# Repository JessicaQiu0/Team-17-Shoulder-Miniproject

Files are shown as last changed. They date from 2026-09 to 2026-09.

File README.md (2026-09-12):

# 03-Miniproject-2026-27

This is a template repo for a multi-disciplinary mini-project for a
small team of EEs, CEs, MEs, and BMEs. The mini-project is described in the
course assignment. You should tailor this repo based on your team
composition, roles, and the tasks at hand.

---

## Team

| Role | Named Members |
|---|---|
| Mechanical Engineering | Elaine Zeng, Marissa Zhai, Sara Mcdermott|
| Electrical Engineering | Jessica Qiu |
| Computer Engineering | Dakota Wang, Melinda Tran|
| Biomedical Engineering | NA |

---

## Repository Structure

```
.
├── firmware/          # Micro source code
├── hardware/
│   ├── electrical/    # Schematics, wiring diagrams, and BOM
│   └── mechanical/    # Enclosure CAD files and fabrication notes
└── docs/              # Project documentation 
```

---

## Hardware

| Component | Notes |
|---|---|
| Seeed XIAO ESP32-S3 | Main microcontroller, runs MicroPython |
| 28BYJ-48 stepper motor | 5-wire, 4-phase unipolar, drives clock hand |
| L293D H-bridge driver | Level-shifts 3.3V logic to 5V motor power |
| RGB LED (common cathode, 4-pin) | PWM-driven per color channel, indicates timer state |
| 2× tactile switches | Preset select + start/pause/reset control |

---

## Team Responsibilities 
Any discipline can do any role here -- you make the assigments. 

### Mechanical oriented
- Design the enclosure 
- Fabricate the enclosure (3-D print or laser-cut)
- Document the assembly process 

### Electrical oriented
- Produce the breadboard schematic
- Summarize the bill of materials
- Wire the circuit on the breadboard, verfify that the componets are assembled correctly, validate the voltage levels

### Computer oriented
- Design the software based on the required functionality
- Develop MicroPython code and firmware 
- Flash and test the firmware on the target micro
- Document the APIs for the system

## Deliverables

- [ ] Functional MicroPython firmware
- [ ] Completed breadboard assembly per schematic
- [ ] Fabricated and assembled enclosure (if MEs on team)
- [ ] Documentation in this repository
- [ ] Video recording demonstrating required function (stored in google drive)

## Contribution Workflow

We want each team member to contribute work products and to host these
including documentation in the repo with version control (software,
firmware, schematics, BOMs, CAD models, etc.) All can be managed in
the repo with version control.

1. Establish that each teammember has properly set up Git/GitHub Desktop
2. Decompose the project into units to assign to each named team member 
3. From the team repo, create a branch from `main` named `<role>/<feature>` (e.g., `me/case`) to capture work artifacts 
4. Fetch the branch to the local laptop
5. Each team member does their work and produces work artifacts and commits these changes to the branch
6. Commit changes with descriptive messages
7. Open a pull request and request review from at least one other team member
8. Merge to main after approval

When performed properly, this workflow leads to an organized set of
work products that are developed concurrently and collaboratively with
version control. This includes the products themselves (e.g.,
firmware, CAD, schematics, etc.) and the associated documentation

Don't know how to do this? Ask your ECE teammates, GSTs, instructors, or AI. 

---

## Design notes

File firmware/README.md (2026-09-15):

# Software README

## Overview
This folder contains the MicroPython firmware for the meeting timer!

There are two main firmware files:

- `main.py` - standard meeting timer firmware (launches `timer_fsm.py` and `stepper_driver.py`)
- `timer_fsm.py` - timer state machine, button debouncing, and PWM breathing logic
- `stepper_driver.py` - motor driver and stepping sequence routines
- `main_low_power.py` - meeting timer firmware with added low-power behavior (When the timer is not actively running, the ESP32 enters short 50 ms light sleep periods to reduce power use while still remaining responsive to button presses and LED updates)
- `full_main.py` - complete, unified meeting timer firmware implementing hardware initialization, event loops, finite state machine transitions, dynamic step tracking, and PWM breathing routines`

The firmware controls:
- the stepper motor
- two push buttons
- three LEDs
- timer preset selection
- countdown behavior
- pause/resume behavior
- reset behavior

The timer supports four preset times:
- 15 minutes
- 20 minutes
- 25 minutes
- 30 minutes

## Pin Assignments

| Component | GPIO Pin |
|---|---:|
| Stepper Motor Coil 1 | GPIO 1 |
| Stepper Motor Coil 2 | GPIO 2 |
| Stepper Motor Coil 3 | GPIO 3 |
| Stepper Motor Coil 4 | GPIO 4 |
| Button 1 | GPIO 5 |
| Button 2 | GPIO 6 |
| Blue LED | GPIO 7 |
| Red LED  | GPIO 8 |
| Green LED| GPIO 9 |

## Controls

### Button 1
Button 1 cycles through the preset timer values:

15 → 20 → 25 → 30 → 15

When a preset is selected, the stepper motor moves the clock hand to the corresponding position.

### Button 2
Button 2 controls the timer:

A short press:
- starts the timer
- pauses the timer while running
- resumes the timer while paused
- resets the timer after it finishes

Holding Button 2 for 2 seconds resets the timer and moves the hand back to 0.

## LED States
The LEDs indicate the current timer state:

- Blue: selecting a preset or paused
- Green: countdown running
- Red: countdown finished

The LEDs are controlled using PWM so the active LED pulses instead of remaining constantly on.

## Timer States

The firmware uses four states:

```python
SELECTING = 0
RUNNING = 1
PAUSED = 2
FINISHED = 3

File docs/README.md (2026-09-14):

# Project Documentation

## Contents

| File | Description |
|---|---|
| project_overview.md | High-level goals, description, usage, and deliverables |
| Mini project photo.jpeg | Photo of the completed device |

---

## Quick Links

- [Firmware](../firmware/)
- [Electrical](../hardware/electrical/)
- [Enclosure](../hardware/mechanical/)

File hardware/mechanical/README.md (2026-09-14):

# Mechanical

## Contents

| File | Description |
| --- | --- |
| `Box.stl` | 3D-printable enclosure body |
| `Assembly 1.stl`  | Complete enclosure assembly for visualization and fit checking |
| `Box Drawing.dxf` | 2D drawing of the enclosure body |
| `Lid Drawing.dxf` | 2D drawing of the enclosure lid |
| `Lid DXF.dxf` | Clock face design used for engraving the lid |
| `Pointer.dxf` | DXF used to cut popsicle stick |

## Overview

The mechanical design consists of a 3D-printable enclosure and lid that house the timer's electrical components and support the stepper motor used to drive the mechanical countdown display.

The enclosure was designed to keep the overall construction simple while providing the necessary mounting and access features for the electronics. The design includes a pathway for the external USB-C cable and a secure mounting location for the stepper motor.

To give the device the appearance of a physical clock rather than a generic electronics enclosure, the team decided to use a clock-inspired aesthetic. A clock face was added to the lid as an engraving, with the stepper motor positioned so that its shaft can drive the external clock hand. The popsicle stick was laser cut to be shorter to accommodate the LED and have a tip that aligns with the clock ticks.

## Enclosure Design

### Box

The box forms the main body of the enclosure and provides space for the microcontroller, motor driver, wiring, and other electrical components.

The enclosure was designed with the following considerations:

* Sufficient internal space for the electrical components and wiring
* A pathway for the USB-C cable for power and programming
* Simple geometry to make the enclosure easy to manufacture and assemble
* Compatibility with the separate lid

The printable enclosure geometry is provided in `Box.stl`, while `Box Drawing.dxf` contains the corresponding 2D drawing.

### Lid

The lid closes the enclosure and serves as the visible clock face of the timer. It includes the features needed to integrate the mechanical countdown display with the enclosure.

The lid was designed to:

* Support the stepper motor securely
* Allow the motor shaft to extend through the lid and connect to the clock hand
* Provide a clock-style front face for the timer
* Fit with the main enclosure for assembly

The lid drawing is provided in `Lid Drawing.dxf`.

## Clock Face

The team decided to give the enclosure a clock-inspired appearance to better communicate the timer's function.

A clock face design was created for engraving onto the lid. This adds numerical markings directly to the enclosure rather than requiring separate labels or components.

The engraving geometry is provided in `Lid DXF.dxf`.

## Stepper Motor Integration

The enclosure is designed around the 28BYJ-48 stepper motor used for the timer's mechanical countdown display.

The motor is mounted to the lid so that its output shaft passes through the clock face. A clock hand can then be attached to the shaft and rotated as the timer counts down.

The motor mounting geometry was designed to keep the motor securely positioned and aligned with the center of the clock face.

## Assembly

The complete enclosure consists of the box, lid, stepper motor, internal electronics, and external clock hand.

`Assembly 1.stl` provides the assembled geometry and can be used to visualize the completed enclosure and verify the relationship between the individual mechanical components.

## Manufacturing and Assembly Notes

The box and lid are designed to be 3D printed as separate components.

Before final assembly:

1. Check that the stepper motor fits correctly in its mounting location.
2. Verify that the motor shaft is aligned with the center of the clock face.
3. Confirm that the USB-C cable can pass through the enclosure without interference.
4. Install the electrical components and route the wiring inside the enclosure.
5. Attach the lid to the enclosure.
6. Attach the clock hand to the stepper motor shaft.

The clock face engraving should be added to the lid before final assembly.

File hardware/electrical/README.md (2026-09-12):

# Electrical

## Contents

| File | Description |
|---|---|
| `Electrical_Schematic.pdf` | Full circuit schematic |
| `Electrical_Schematic.kicad_sch` | Editable KiCad source file |

## Overview

This circuit implements a timer with a mechanical countdown display. A user selects a preset time (15/20/25/30 min) and starts the timer using two buttons. As time counts down, a stepper motor rotates a clock hand to show time remaining, while an RGB LED pulses to indicate the timer's status (e.g., running, paused, or finished).

**Motor control:** Since the XIAO's GPIO pins output 3.3V and can't directly drive the motor, an L293D H-bridge driver sits between them. It takes the 3.3V logic signals and switches the motor's 5V power accordingly. The stepper is driven using wave-pulse sequencing (energizing one coil at a time in sequence) to rotate the clock hand.

**LED feedback:** A common-cathode RGB LED, current-limited with 220Ω resistors on each color leg, is PWM-driven by the microcontroller to pulse and change color based on timer state.

**User input:** Two push buttons let the user select a preset and control start/pause/reset, read directly by the microcontroller's GPIO pins.

## Pin Mapping

### XIAO ESP32-S3 → L293D (motor control)

| XIAO Pin | L293D Pin | Function |
|---|---|---|
| GPIO1 | Pin 2 (1A) | Motor coil 1 signal |
| GPIO2 | Pin 7 (2A) | Motor coil 2 signal |
| GPIO3 | Pin 10 (3A) | Motor coil 3 signal |
| GPIO4 | Pin 15 (4A) | Motor coil 4 signal |

### L293D → Motor (28BYJ-48)

| L293D Pin | Motor Wire |
|---|---|
| Pin 3 (1Y) | Orange (Coil 1) |
| Pin 6 (2Y) | Pink (Coil 2) |
| Pin 11 (3Y) | Yellow (Coil 3) |
| Pin 14 (4Y) | Blue (Coil 4) |
| — | Red (+5V, direct to 5V rail) |

### XIAO ESP32-S3 → RGB LED (via 220Ω resistors)

| XIAO Pin | LED Leg |
|---|---|
| GPIO7 | Blue |
| GPIO8 | Red |
| GPIO9 | Green |
| GND/13 | Common leg → GND |

### XIAO ESP32-S3 → Buttons

| XIAO Pin | Button |
|---|---|
| GPIO5 | Button 1 (other leg → GND) |
| GPIO6 | Button 2 (other leg → GND) |

### Power & Ground

| XIAO Pin | Connects To |
|---|---|
| 3.3V | L293D VCC1 (Pin 16), EN1,2 (Pin 1), EN3,4 (Pin 9) |
| 5V | L293D VCC2 (Pin 8), Motor Red wire |
| GND | L293D GND (Pins 4, 5, 12, 13), LED common leg, both buttons |

## Bill of Materials

| Part | Qty | Source | Unit Cost | Notes |
|---|-----|---|---|---|
| Seeed XIAO ESP32-S3 | 1 | Digikey | $7.49 | Main microcontroller |
| L293D H-bridge driver | 1 | Digikey | $8.86 | Level-shifts 3.3V logic to 5V motor power |
| 28BYJ-48 stepper motor | 1 | Adafruit | $4.95 | Drives clock hand; no clean single-unit listing found |
| RGB LED (common cathode, 4-pin) | 1 | Digikey | $2.66 | PWM-driven, indicates timer state |
| Tactile switch | 2 | Digikey | $0.10 | Button 1 (preset select), Button 2 (start/pause/reset) |
| 220Ω resistor | 3 | Digikey | $0.10| LED current limiting |
| USB-C cable | 1 | — | — | Power + programming |
| Popsicle stick | 1 | — | — | Clock hand |
| Jumper wires | — | — | — | Breadboard connections |

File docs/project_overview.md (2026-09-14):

# Project Overview

## Goal

Build a self-contained meeting timer with a mechanical display. The device lets a user select a preset duration, start/pause/reset the countdown, and see time remaining via a rotating clock hand while an RGB LED indicates the timer's current status. This project help our team to establish our GitHub workflow, collaborative process, and hardware-software development environment ahead of our Senior Design project.

## Description of Device

The meeting timer is built around a Seeed XIAO ESP32-S3 running MicroPython. A 28BYJ-48 stepper motor, driven through an L293D H-bridge, rotates a physical clock hand to show time remaining, moving from the selected preset position down to zero as the countdown progresses. An RGB LED communicates the current state through color and pulsing: blue for Selecting/Paused, green for Running, red for Finished. Two tactile buttons handle all user input. There is no screen, no wireless connection, and all of it is fully self-contained.

## Photo

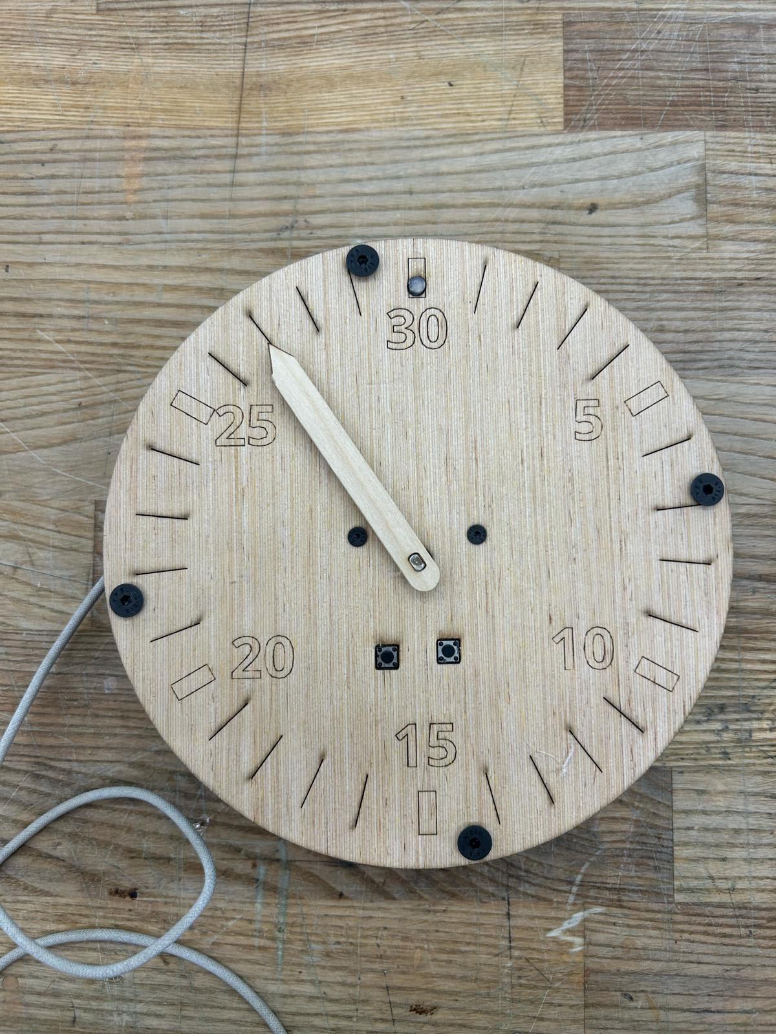
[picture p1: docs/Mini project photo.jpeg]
Meeting timer device


## Demo Video

[Watch the device in operation](https://drive.google.com/file/d/1FZ5ZU9aSdHHcK9WmNDZN5K3bjihf6jEc/view?usp=drive_link)

## How to Use It

1. Power on the device via USB-C. The hand returns to the zero position.
2. Press **Button 1** to cycle through the four presets (15 / 20 / 25 / 30 minutes). The hand moves to reflect the selected duration.
3. Press **Button 2** to start the countdown. The hand begins moving toward zero and the LED switches to green.
4. Press **Button 2** again at any time to pause (LED returns to blue) or resume (LED returns to green).
5. Hold **Button 2** for 2 seconds at any point to reset the timer back to the selection state.
6. When the countdown reaches zero, the LED turns red and the hand returns to zero. Press **Button 2** to reset and select a new preset.

## Deliverables

- Working meeting timer with 15/20/25/30 minute presets
- Mechanical clock hand (stepper motor-driven) showing time remaining
- Two buttons for timer control (preset selection, start/pause/reset)
- RGB LED status indicator (PWM-pulsed)
- 3D-printed enclosure housing all components
- Full documentation: electrical schematic, firmware code, mechanical CAD, and a state chart/flowchart of system operation

## References

- Seeed Studio XIAO ESP32-S3 documentation
- MicroPython ESP32-S3 documentation
- L293D datasheet
- 28BYJ-48 stepper motor datasheet

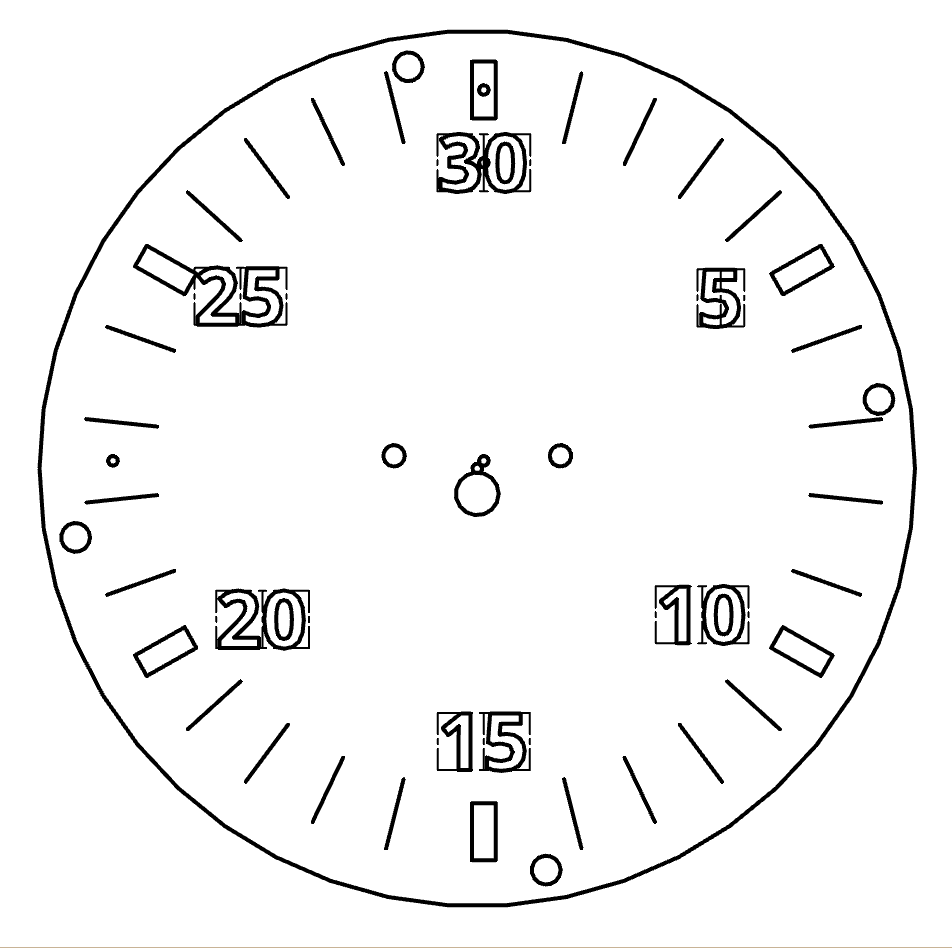
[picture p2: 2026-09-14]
hardware/mechanical/Clock face sketch.png

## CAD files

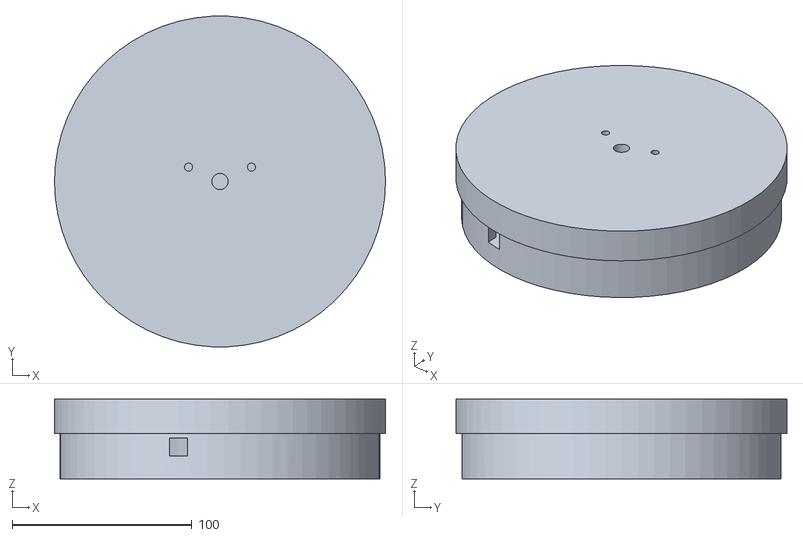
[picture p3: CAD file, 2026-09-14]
hardware/mechanical/Assembly 1.stl
184.1 x 183.9 x 44.4

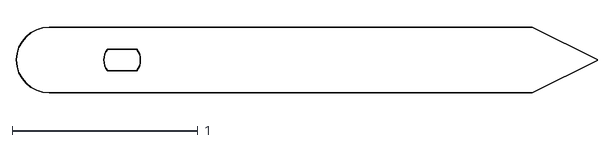
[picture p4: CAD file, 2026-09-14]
hardware/mechanical/Pointer.dxf
3.13 x 0.354

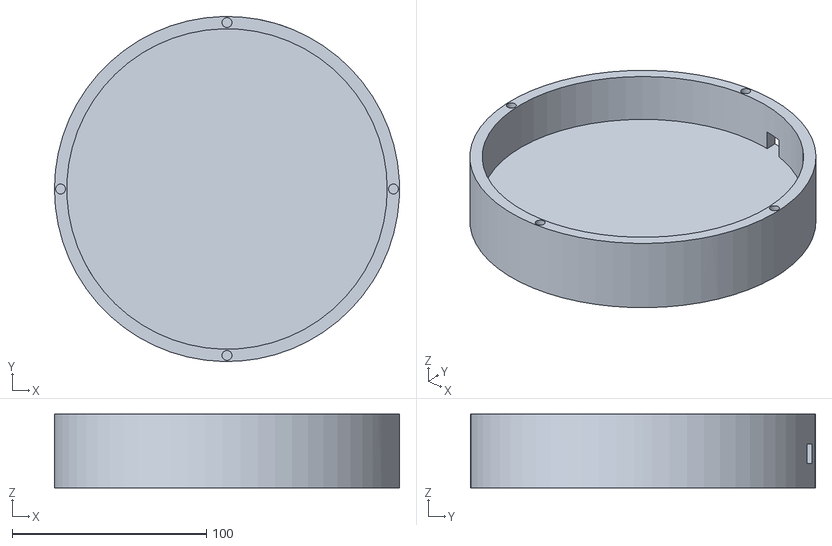
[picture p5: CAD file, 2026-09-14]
hardware/mechanical/Box.stl
177.8 x 177.7 x 38.1

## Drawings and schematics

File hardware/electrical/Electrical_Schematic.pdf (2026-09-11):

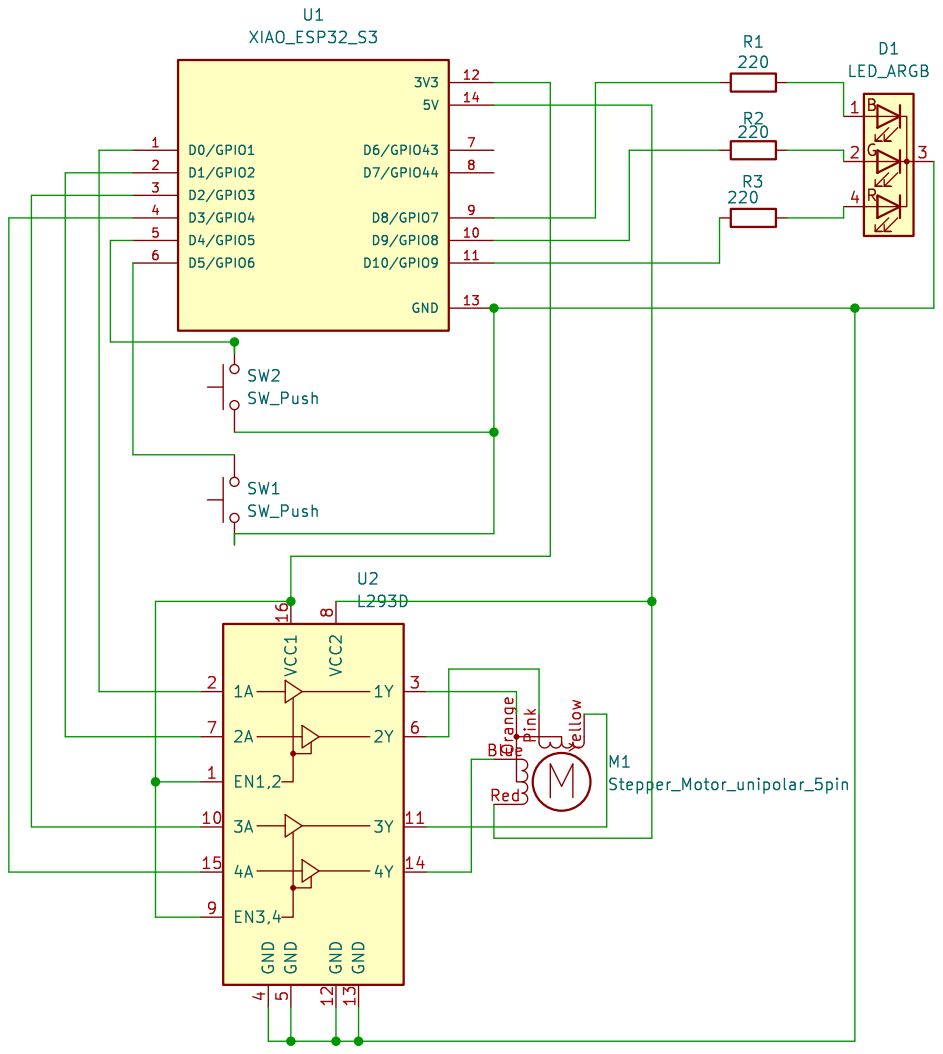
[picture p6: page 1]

Id: 1/1 Title: File: Electrical_Schematic.kicad_sch Sheet: / EN1,2 1

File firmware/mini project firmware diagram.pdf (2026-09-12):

15/ 20/25/30
ㅇ

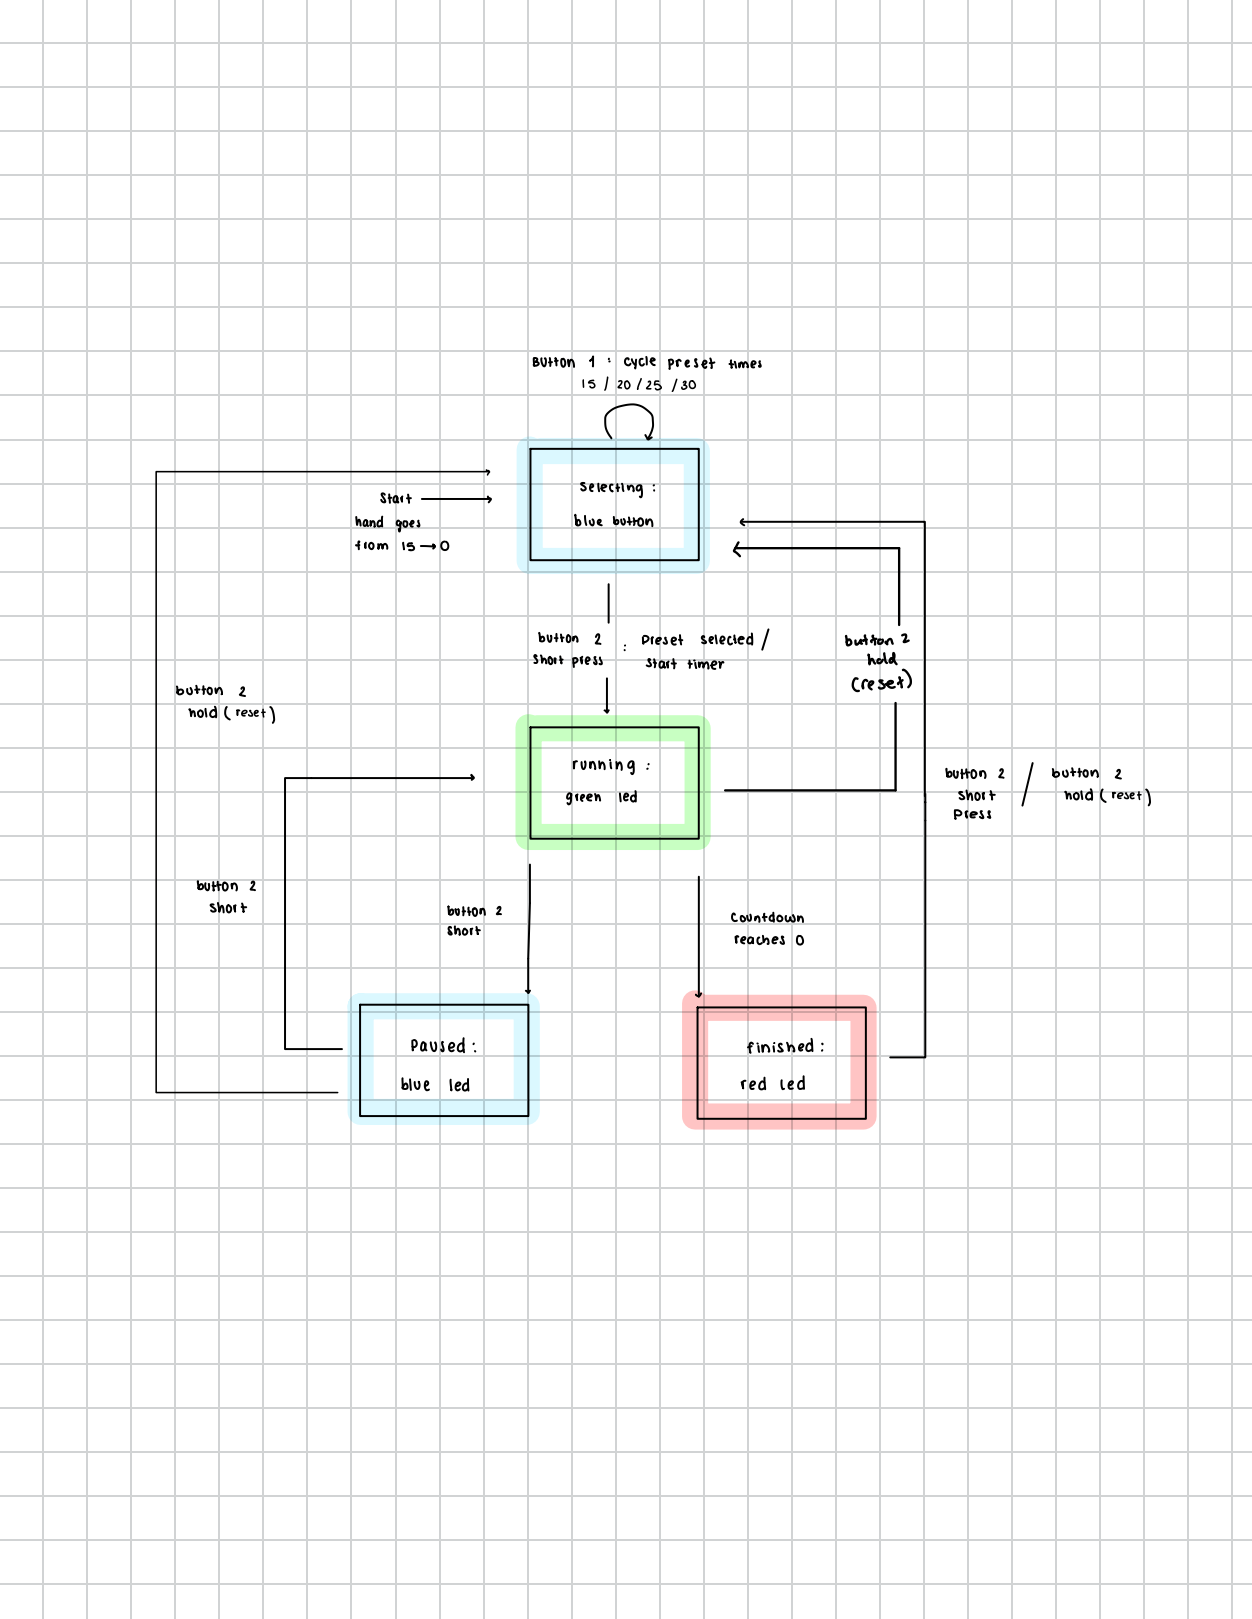
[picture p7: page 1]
Button; cycle; preset times; Start; from; hand; goes; button; Preset; selected .; short; press; start timer; hold; (reset); button 2; Mining green; led; hold 받; (reset) rt; Short; countdown reaches; paused :; Minisbed:; blue; red led; button 2 hold Creset)

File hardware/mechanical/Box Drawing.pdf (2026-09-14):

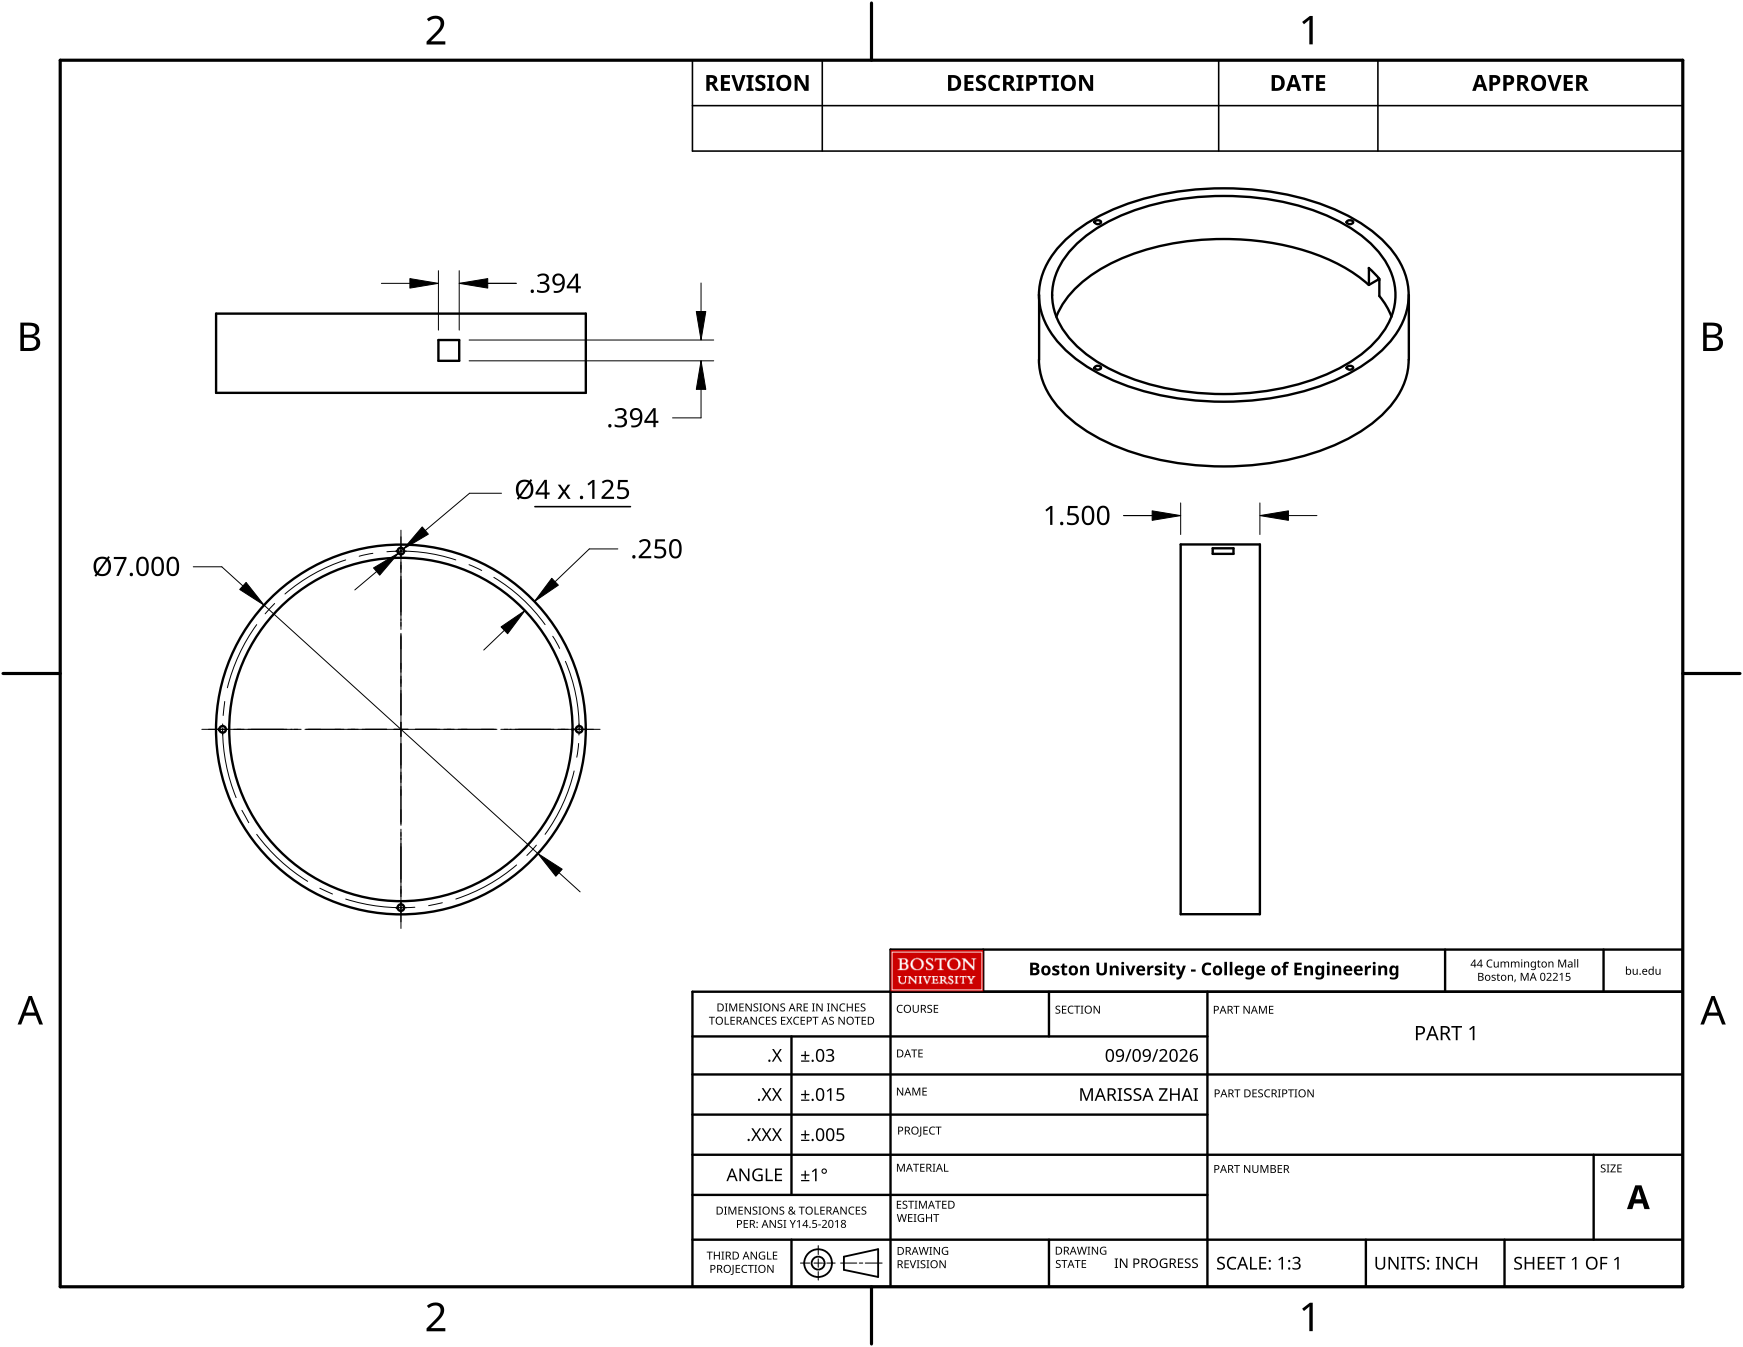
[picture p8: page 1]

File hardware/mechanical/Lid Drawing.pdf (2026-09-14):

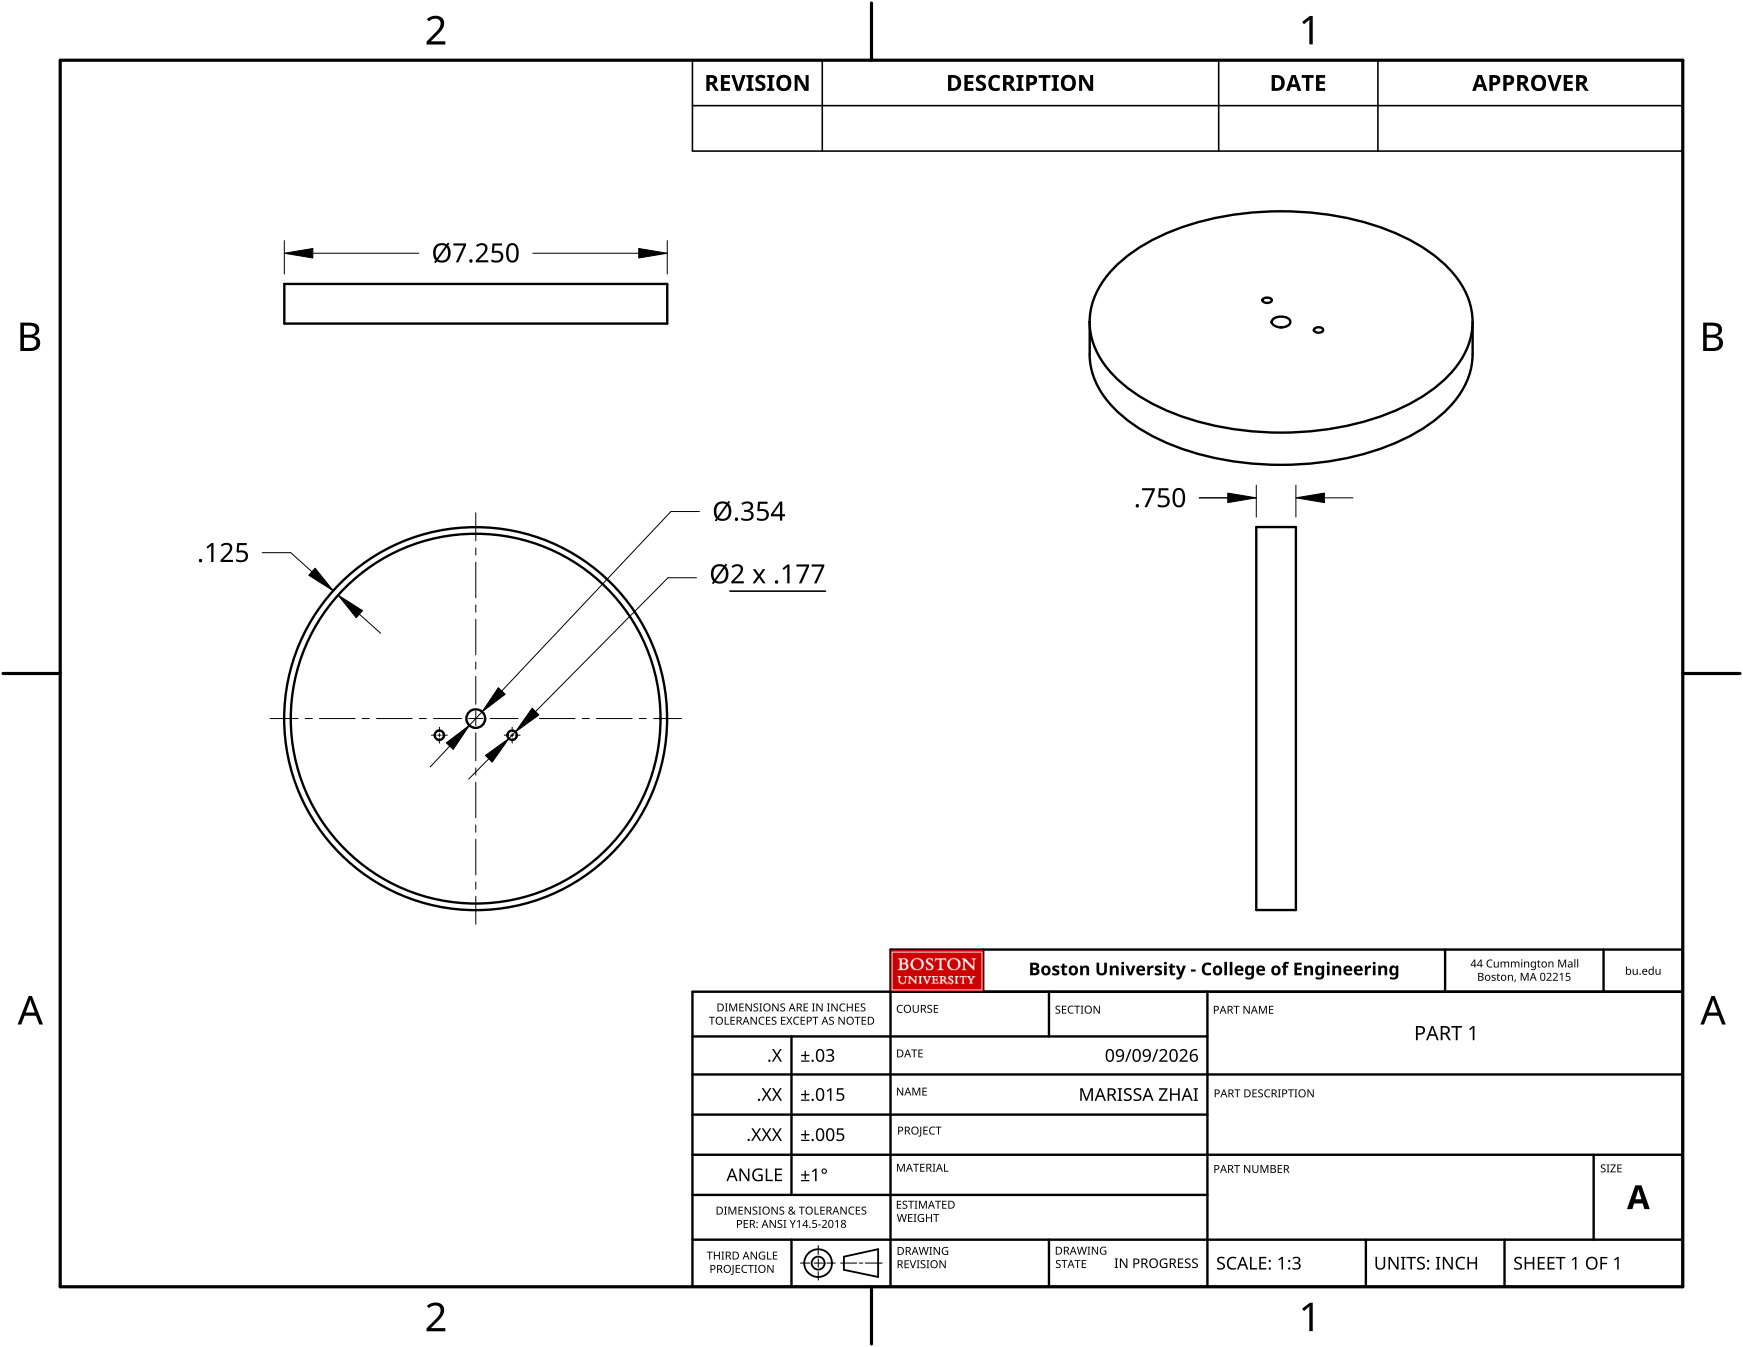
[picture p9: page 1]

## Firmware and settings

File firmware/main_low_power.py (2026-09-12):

# mini project code in minutes

from machine import Pin, PWM
import machine
import time


#pins
motor = [
    Pin(1, Pin.OUT),
    Pin(2, Pin.OUT),
    Pin(3, Pin.OUT),
    Pin(4, Pin.OUT)
]

button1 = Pin(5, Pin.IN, Pin.PULL_UP)
button2 = Pin(6, Pin.IN, Pin.PULL_UP)

#led wiring
blue = PWM(Pin(7))
red = PWM(Pin(8))
green = PWM(Pin(9))

blue.freq(1000)
red.freq(1000)
green.freq(1000)


#motor
sequence = [
    [1, 0, 0, 0],
    [0, 1, 0, 0],
    [0, 0, 1, 0],
    [0, 0, 0, 1]
]

step_index = 0
current_position = 0

#30 minutes is one full rotation
FULL_30_MIN_STEPS = 2048

def single_step(direction):
    global step_index
    global current_position

    # change direction to negative to rotate the right way
    actual_direction = -direction

    step_index = (step_index + actual_direction) % 4
    step = sequence[step_index]

    for pin, value in zip(motor, step):
        pin.value(value)

    current_position += direction
    time.sleep_ms(5)

def motor_off():
    for pin in motor:
        pin.value(0)

def minutes_to_steps(minutes):
    return int(FULL_30_MIN_STEPS * minutes / 30)

def move_to_minutes(minutes):
    global current_position

    target = minutes_to_steps(minutes)

    while current_position < target:
        single_step(1)

    while current_position > target:
        single_step(-1)

    motor_off()


#presets that are pre allocated 
presets = [15, 20, 25, 30]

preset_index = -1
selected_minutes = 0

remaining_ms = 0
total_time_ms = 0
last_update = 0


#states of the timer
SELECTING = 0
RUNNING = 1
PAUSED = 2
FINISHED = 3

state = SELECTING


#leds
def leds_off():
    red.duty_u16(0)
    green.duty_u16(0)
    blue.duty_u16(0)

def update_leds():
    cycle = time.ticks_ms() % 1000

    if cycle < 500:
        brightness = int(cycle / 500 * 65535)
    else:
        brightness = int((1000 - cycle) / 500 * 65535)

    leds_off()

    #blue state is when selecting or paused
    if state == SELECTING or state == PAUSED:
        blue.duty_u16(brightness)

    # green state is when running
    elif state == RUNNING:
        green.duty_u16(brightness)

    # red state is when finished
    elif state == FINISHED:
        red.duty_u16(brightness)


# preset selection
def next_preset():
    global preset_index
    global selected_minutes
    global remaining_ms
    global total_time_ms

    preset_index = (preset_index + 1) % len(presets)

    selected_minutes = presets[preset_index]

    #NOTE TO SELF:
    # delete the *60 if you want it to move in terms of seconds for testing purposes
    total_time_ms = selected_minutes * 60 * 1000
    remaining_ms = total_time_ms

    print("selected:", selected_minutes, "minutes")

    #move hand to the selected physical position
    move_to_minutes(selected_minutes)


# timer control

def start_timer():
    global state
    global last_update

    state = RUNNING
    last_update = time.ticks_ms()

    print("countdown started")


def pause_timer():
    global state

    state = PAUSED
    motor_off()

    print("paused")


def resume_timer():
    global state
    global last_update

    state = RUNNING
    last_update = time.ticks_ms()

    print("resumed")


def reset_timer():
    global state
    global remaining_ms
    global total_time_ms
    global selected_minutes
    global preset_index

    print("resetting to 0")

    #return hand to zero
    move_to_minutes(0)

    #clear the selected timer
    remaining_ms = 0
    total_time_ms = 0
    selected_minutes = 0
    preset_index = -1

    state = SELECTING

    print("reset complete")
    print("hand at 0")
    print("select a new preset")


# countdown
def update_timer():
    global remaining_ms
    global last_update
    global state
    global current_position

    if state != RUNNING:
        return

    now = time.ticks_ms()

    elapsed = time.ticks_diff(now, last_update)
    last_update = now

    remaining_ms -= elapsed

    #timer finished
    if remaining_ms <= 0:
        remaining_ms = 0

        while current_position > 0:
            single_step(-1)

        motor_off()

        state = FINISHED

        print("time is up!!!")

        return

    #percentage of time remaining
    fraction_remaining = remaining_ms / total_time_ms

    #original physical preset position
    starting_position = minutes_to_steps(selected_minutes)

    #move gradually toward 0
    target_position = int(
        starting_position * fraction_remaining
    )

    if current_position > target_position:
        single_step(-1)
        motor_off()


# button 1 code
def handle_button1():

    if state != SELECTING:
        return

    if button1.value() == 0:
        time.sleep_ms(30)

        if button1.value() == 0:

            next_preset()

            while button1.value() == 0:
                update_leds()
                time.sleep_ms(10)

            time.sleep_ms(30)

# button 2 code
def handle_button2():
    global state

    if button2.value() != 0:
        return

    time.sleep_ms(30)

    if button2.value() != 0:
        return

    press_start = time.ticks_ms()

    while button2.value() == 0:

        update_leds()

        held_time = time.ticks_diff(
            time.ticks_ms(),
            press_start
        )

        #hold for 2 seconds to reset to zero
        if held_time >= 2000:

            reset_timer()

            while button2.value() == 0:
                time.sleep_ms(10)

            return

        time.sleep_ms(10)

    time.sleep_ms(30)

    #short press
    if state == SELECTING:

        if selected_minutes > 0:
            start_timer()
        else:
            print("select a preset first")

    elif state == RUNNING:
        pause_timer()

    elif state == PAUSED:
        resume_timer()

    elif state == FINISHED:
        reset_timer()


#low power mode
def low_power_idle():

    #if the timer is not actively running, reduce power use
    if state != RUNNING:

        #turn off the motor coils when the motor is not moving
        motor_off()

        #put the esp32 into light sleep for 50 milliseconds
        #it automatically wakes up and checks the buttons again
        machine.lightsleep(50)


# startup code
leds_off()
motor_off()

print()
print("meeting timer")
print()

#this line assumes the hand is physically at 15 when code starts
current_position = minutes_to_steps(15)

print("returning hand from 15 to 0")
move_to_minutes(0)

print("hand is at 0")
print()
print("button 1 = select 15 / 20 / 25 / 30 minutes")
print("button 2 = start / pause / resume")
print("hold button 2 = reset to 0")
print()


#main loop
while True:
    update_leds()
    handle_button1()
    handle_button2()
    update_timer()
    low_power_idle()
    time.sleep_ms(5)

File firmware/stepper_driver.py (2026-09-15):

# Low-level stepper motor hardware driver and GPIO interface for Seeed XIAO ESP32-S3.

import time
from machine import Pin

# Define discrete digital outputs to L293D inputs
motor_pins = [
    Pin(1, Pin.OUT),  # 1A -> Pin 2
    Pin(2, Pin.OUT),  # 2A -> Pin 7
    Pin(3, Pin.OUT),  # 3A -> Pin 10
    Pin(4, Pin.OUT),  # 4A -> Pin 15
]

# 4-phase wave drive excitation sequence (one coil energized at a time)
WAVE_SEQUENCE = [[1, 0, 0, 0], [0, 1, 0, 0], [0, 0, 1, 0], [0, 0, 0, 1]]

# 28BYJ-48 gear ratio and resolution calibration
FULL_ROTATION_STEPS = 2048  # 360-degree rotation constant
step_index = 0
current_position = 0


def single_step(direction):
  """Advance the motor by a single wave step with reversed polarity correction."""
  global step_index, current_position
  actual_direction = -direction
  step_index = (step_index + actual_direction) % len(WAVE_SEQUENCE)
  step_pattern = WAVE_SEQUENCE[step_index]

  for pin, state in zip(motor_pins, step_pattern):
    pin.value(state)

  current_position += direction
  time.sleep_ms(5)


def deenergize_coils():
  """Set all coil pins to 0 to eliminate static holding current and thermal dissipation."""
  for pin in motor_pins:
    pin.value(0)


def minutes_to_steps(minutes, dial_span_minutes=30):
  """Convert time in minutes to target step position across dial geometry."""
  return int(FULL_ROTATION_STEPS * (minutes / dial_span_minutes))


def sweep_to_position(target_steps):
  """Sweep pointer arm to absolute angular step coordinate."""
  global current_position
  while current_position < target_steps:
    single_step(1)
  while current_position > target_steps:
    single_step(-1)
  deenergize_coils()


def get_current_position():
  return current_position

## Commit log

2026-09-11 Update README with firmware file descriptions
    Added details about main firmware files and low-power behavior.
2026-09-14 Update README with popsicle stick details
    Added information about the popsicle stick used for the clock hand alignment and LED accommodation.
2026-09-15 implement modular timer FSM, button debouncing, and main launch (#10)
2026-09-15 create seperate file timer_fsm.py
2026-09-15 Add stepper motor driver for Seeed XIAO ESP32-S3
